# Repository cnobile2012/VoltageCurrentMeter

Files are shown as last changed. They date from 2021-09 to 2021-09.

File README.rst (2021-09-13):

*********************
Voltage Current Meter
*********************
The MIT License (MIT)

A circuit to show voltage and current on a TFT display. Parts can be added
using a small array of mounting holes on the board, plus two daughter boards
can be plugged into female connectors. There is an on board 5V to 3.3V
regulator which powers all components.

=====
KiCAD
=====

KiCAD files of the schematic and PCB.

==================
Setup Instructions
==================

  1. J1 - J8 are JST 1.5mm 3-pin connectors and are for the analog inputs or
     outputs of the 74HC4051 (8-Channel Analog Multiplexer/Demultiplexer).
  2. J9 is a screw terminal block for the circuits supply voltage.
  3. J10 is the Power Jumper. It allows the use of 5V on J9 or routes the
     V-IN on J9 to  a daughter board which can convert the voltage on J9 to 5V.
  4. J11 is a 4 pin standard female socket for the optional Daughter Board 1.
     This board can be used for external circuitry to convert any voltage to
     the 5 volts needed by the 3.3V regulator.
  5. J12 is a 12 pin standard female socket that provides the 2nd daughter
     board with all the control pins from the 74HC4051. It also provides the
     two pins not used on the Seeeduino XIAO plus ground and 3.3V power.

==============
PCBs Version 1
==============

=========
Schematic
=========

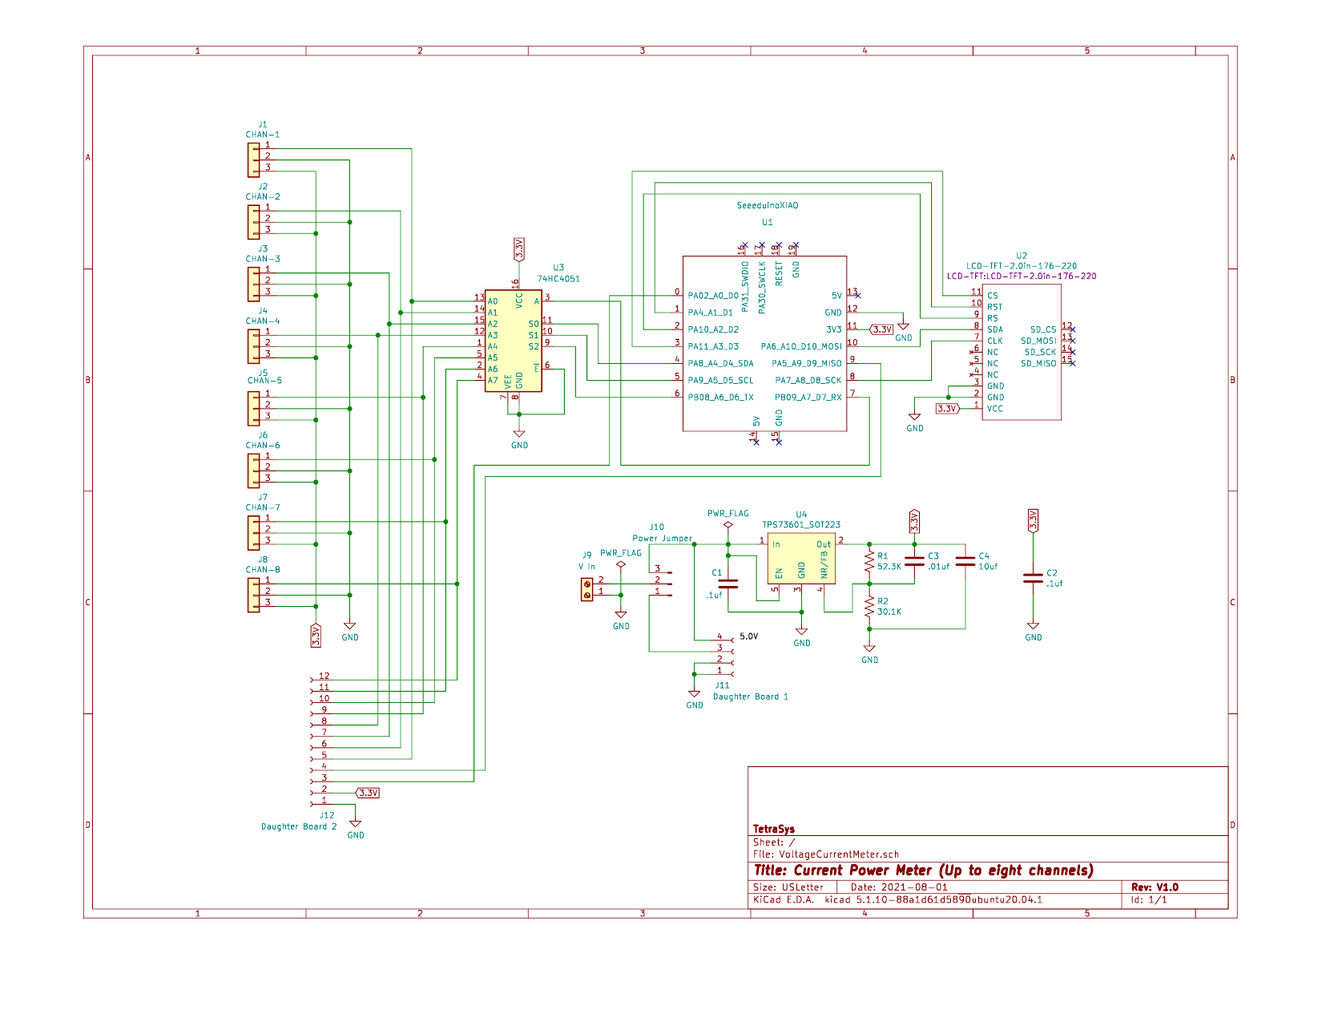
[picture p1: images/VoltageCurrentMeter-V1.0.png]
Schematic


================
Arduino Sketches
================

Below are the sketches that use this board.

--------------
BatteryCharger
--------------

This sketch displays the set voltage and current limited values and the actual
values while charging Li-Ion batteries. The charging voltage is adjustable to
12.6V (3 cells), 16.8V (4 cells), or 21.0V (5 cells) depending on the number of
cells. The default current is limited to 1250mA or can be set to adjustable
using a potentiometer.

Feel free to contact me at: carl dot nobile at gmail.com

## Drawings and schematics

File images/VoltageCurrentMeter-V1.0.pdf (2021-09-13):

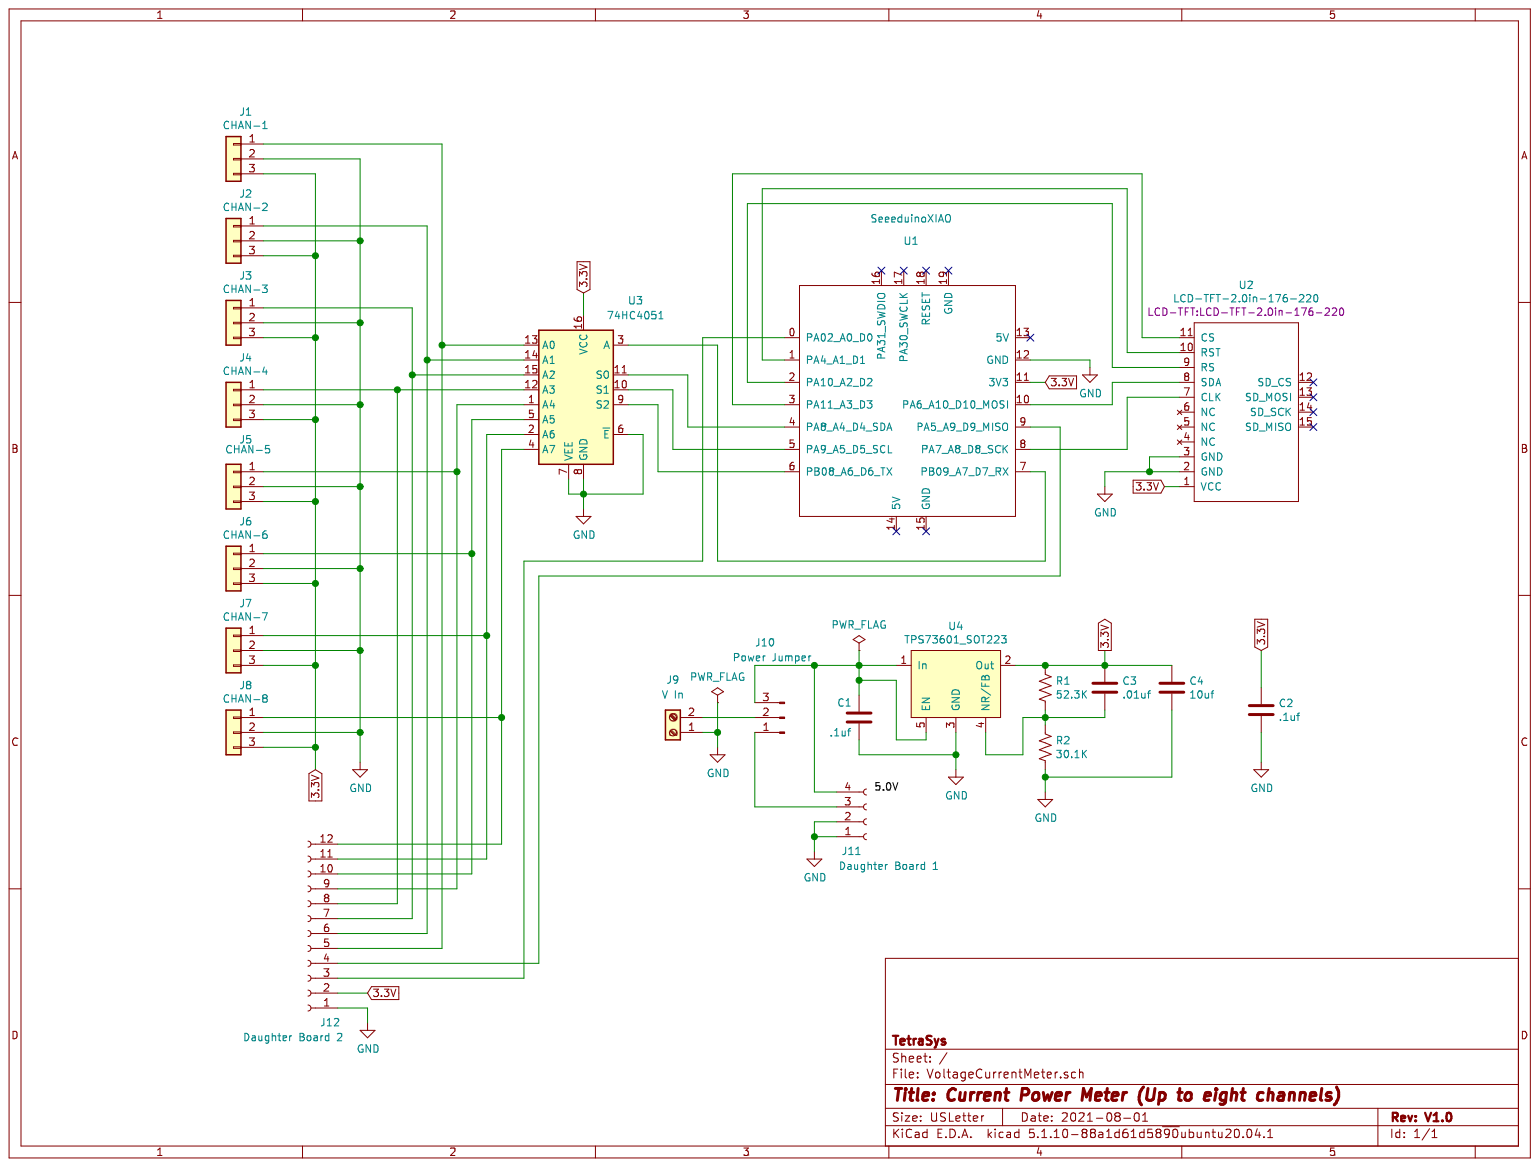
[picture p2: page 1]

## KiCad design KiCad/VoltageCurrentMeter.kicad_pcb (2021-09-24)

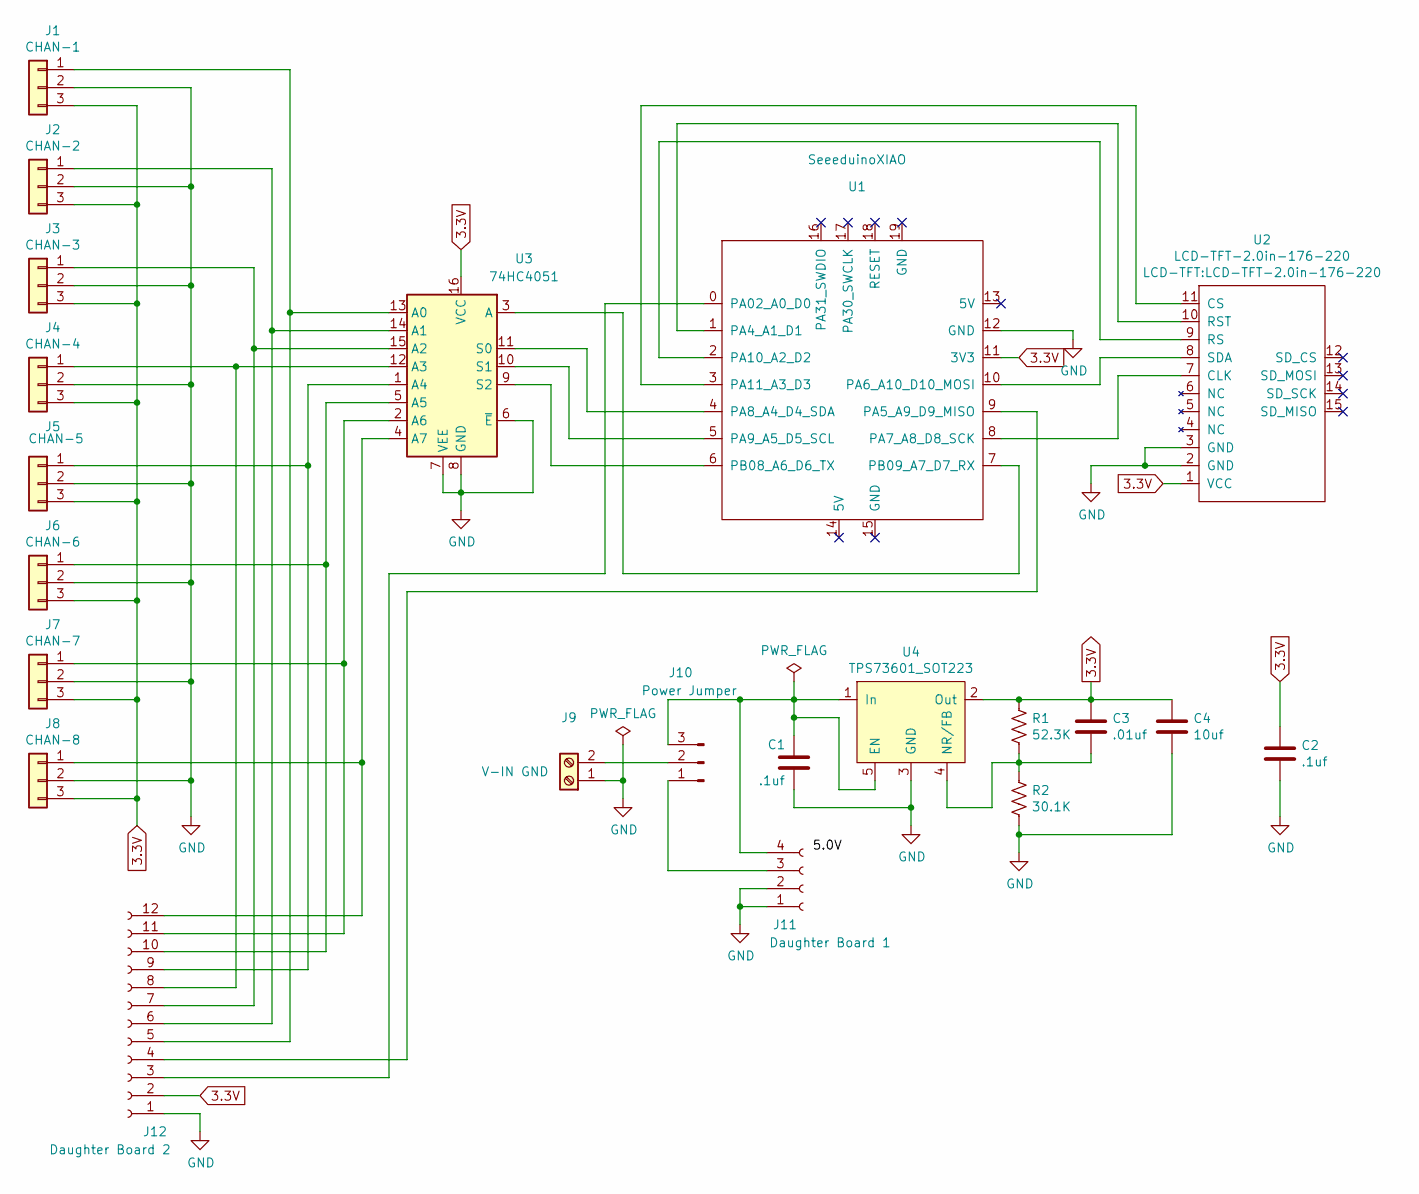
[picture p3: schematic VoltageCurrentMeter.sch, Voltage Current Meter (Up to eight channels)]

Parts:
C1, C2: .1uf; C_Disc_D4.7mm_W2.5mm_P5.00mm
C3: .01uf; C_Disc_D4.7mm_W2.5mm_P5.00mm
C4: 10uf; CP_Radial_D6.3mm_P2.50mm
J1: CHAN-1; JST_CJN_1x03_P1.50mm_Vertical
J2: CHAN-2; JST_CJN_1x03_P1.50mm_Vertical
J3: CHAN-3; JST_CJN_1x03_P1.50mm_Vertical
J4: CHAN-4; JST_CJN_1x03_P1.50mm_Vertical
J5: CHAN-5; JST_CJN_1x03_P1.50mm_Vertical
J6: CHAN-6; JST_CJN_1x03_P1.50mm_Vertical
J7: CHAN-7; JST_CJN_1x03_P1.50mm_Vertical
J8: CHAN-8; JST_CJN_1x03_P1.50mm_Vertical
J9: V-IN GND; TerminalBlock_Phoenix_MKDS-1,5-2-5.08_1x02_P5.08mm_Horizont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
J10: Power Jumper; PinHeader_1x03_P2.54mm_Vertical
J11: Daughter Board 1; PinSocket_1x04_P2.54mm_Vertical
J12: Daughter Board 2; PinSocket_1x12_P2.54mm_Vertical
R1: 52.3K; R_Axial_DIN0207_L6.3mm_D2.5mm_P10.16mm_Horizontal
R2: 30.1K; R_Axial_DIN0207_L6.3mm_D2.5mm_P10.16mm_Horizontal
U1: SeeeduinoXIAO; SeeeduinoXIAO-MOUDLE14P-2.54-21X17.8MM
U2: LCD-TFT-2.0in-176-220
U3: 74HC4051; SO-16_3.9x9.9mm_P1.27mm
U4: TPS73601_SOT223; SOT-223-6_TabPin3

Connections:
3.3V: C2.1, C3.1, C4.1, J1.3, J2.3, J3.3, J4.3, J5.3, J6.3, J7.3, J8.3, J12.2, R1.1, U1.11 (3V3), U2.1 (VCC), U3.16 (VCC), U4.2 (Out)
GND: C1.2, C2.2, C4.2, J1.2, J2.2, J3.2, J4.2, J5.2, J6.2, J7.2, J8.2, J9.1, J11.1, J11.2, J12.1, R2.2, U1.12 (GND), U2.2 (GND), U2.3 (GND), U3.6 (~E), U3.7 (VEE), U3.8 (GND), U4.3 (GND)
unnamed: C1.1, J10.3, J11.4, U4.1 (In), U4.5 (EN)
unnamed: C3.2, R1.2, R2.1, U4.4 (NR/FB)
unnamed: J1.1, J12.5, U3.13 (A0)
unnamed: J10.1, J11.3
unnamed: J9.2, J10.2
unnamed: J12.3, U1.0 (PA02_A0_D0)
unnamed: J12.4, U1.9 (PA5_A9_D9_MISO)
unnamed: J2.1, J12.6, U3.14 (A1)
unnamed: J3.1, J12.7, U3.15 (A2)
unnamed: J4.1, J12.8, U3.12 (A3)
unnamed: J5.1, J12.9, U3.1 (A4)
unnamed: J6.1, J12.10, U3.5 (A5)
unnamed: J7.1, J12.11, U3.2 (A6)
unnamed: J8.1, J12.12, U3.4 (A7)
unnamed: U1.1 (PA4_A1_D1), U2.10 (RST)
unnamed: U1.2 (PA10_A2_D2), U2.9 (RS)
unnamed: U1.3 (PA11_A3_D3), U2.11 (CS)
unnamed: U1.4 (PA8_A4_D4_SDA), U3.11 (S0)
unnamed: U1.5 (PA9_A5_D5_SCL), U3.10 (S1)
unnamed: U1.6 (PB08_A6_D6_TX), U3.9 (S2)
unnamed: U1.7 (PB09_A7_D7_RX), U3.3 (A)
unnamed: U1.8 (PA7_A8_D8_SCK), U2.7 (CLK)
unnamed: U1.10 (PA6_A10_D10_MOSI), U2.8 (SDA)

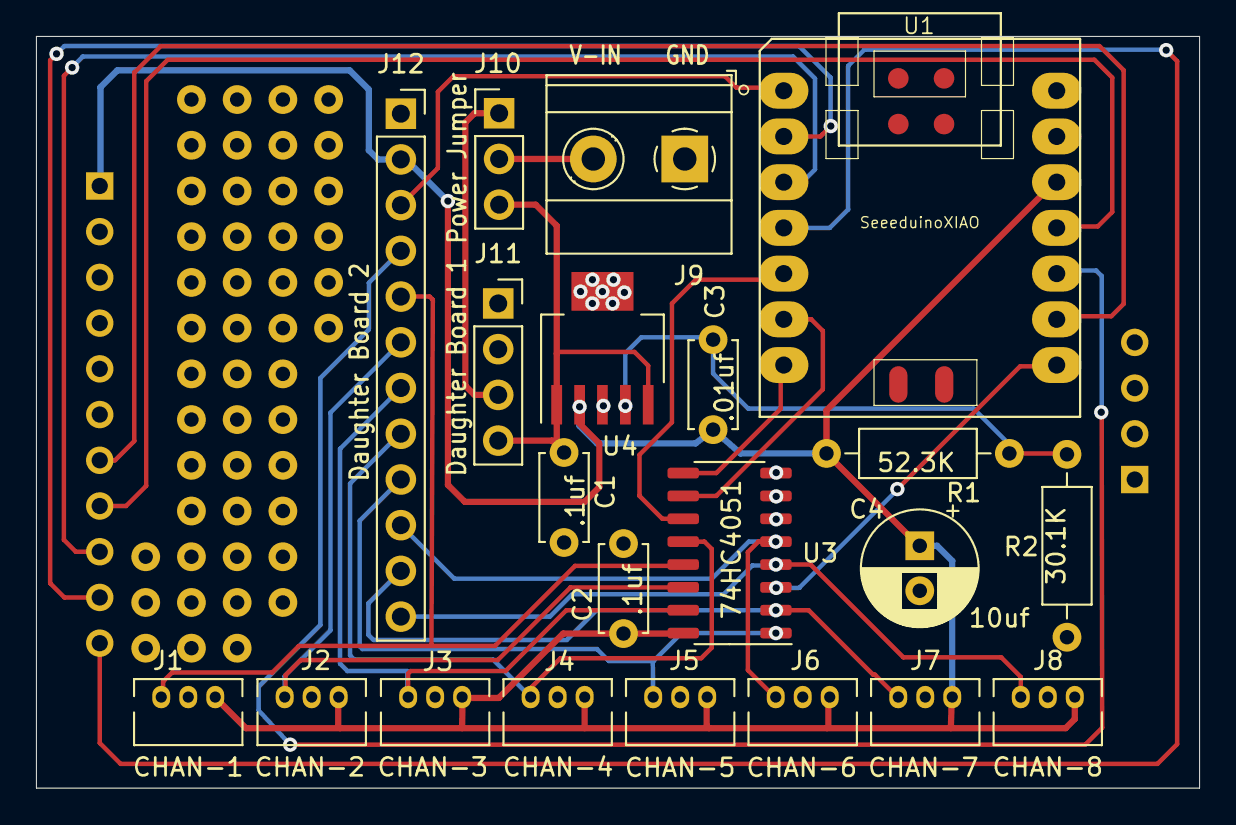
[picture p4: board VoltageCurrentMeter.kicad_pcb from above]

Board: 2 copper layers, 64.6 x 41.8 mm, 22 parts (1 on the bottom side), 25 nets.

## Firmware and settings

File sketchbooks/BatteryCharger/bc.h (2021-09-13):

/*
 * Battery Charger Header
 */

#ifndef  _BC_H
#define  _BC_H

#ifndef TFT_22_ILI9225_h
  #include <TFT_22_ILI9225.h>
#endif

typedef struct
  {
  String text;
  const GFXfont *f;
  uint16_t color;
  int16_t x1;
  int16_t y1;
  int16_t x2;
  int16_t y2;
  } MeterHeaderType;

typedef struct
  {
  String text;
  String old_text;
  bool changed;
  const GFXfont *f;
  uint16_t color;
  int16_t x;
  int16_t y;
  } MeterDataType;

/*
 * Configured for the Seeeduino XIAO
 */
#define TFT_RST 1  // D1
#define TFT_RS  2  // D3
#define TFT_CS  3  // D2
#define TFT_SDI 10 // MOSI
#define TFT_CLK 8  // SCK
#define TFT_LED 0  // D0 -- NC if wired to +3.3V internally.

#define PIN_S0  4  // D4
#define PIN_S1  5  // D5
#define PIN_S2  6  // D6
#define ADC_PIN 7  // A7 (ADC pin)

#define TFT_BRIGHTNESS 200 // Initial brightness of TFT backlight (optional)
#define DEFAULT_METER_COLOR COLOR_GOLD
#define DEFAULT_BACKGROUND_COLOR COLOR_BLACK
#define ERROR_COLOR COLOR_RED

#define NUM_ITEMS(a) (sizeof(a) / sizeof(*a))

#define HEADER_STRUCT_SIZE 4
#define METER_DATA_ARRAY_SIZE 4
// MUX_74HC4051_SIZE -- Voltage, Current, and a switch to
// set voltage and current values.
#define MUX_74HC4051_SIZE 4
#define NUM_READS 200

/*
 * Prototypes
 */
void populateDisplays(void);
void drawHeaders(void);
void initialPopulateData(void);
void drawData(uint16_t color);
void selectChannel(byte counter);
void setChanged(MeterDataType *data, String sensor, uint16_t cn);
uint16_t incSelectCount(uint16_t average, uint16_t select, uint16_t max);
void setVoltage(uint16_t vSelect);
void setCurrent(uint16_t cSelect);

#endif /* _BC_H */

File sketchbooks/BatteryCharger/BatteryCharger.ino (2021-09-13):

// Include application, user and local libraries
//#include <SPI.h>
#include <TFT_22_ILI9225.h>

// This code works with the 2.0in Arduino Color LCD Modual from 
// Include font definition files
// NOTE: These files may not have all characters defined! Check the GFXfont def
// params 3 + 4, e.g. 0x20 = 32 = space to 0x7E = 126 = ~

/*
 * To create these fonts go to http://oleddisplay.squix.ch/#/home
 * Choose the TFT display under Preview Display.
 * Choose "Adafruit GTX Font" under the "Library Version".
 * The rest should be obvious.
 * Copy-n-past to a file as named in the #include below.
 */
#include "Roboto_Mono_Bold_16.h"
#include "Roboto_Mono_Bold_15.h"
#include "bc.h"

#define DEBUG true

// Use hardware SPI (faster - on Uno: 13-SCK, 12-MISO, 11-MOSI)
TFT_22_ILI9225 tft = TFT_22_ILI9225(TFT_RST, TFT_RS, TFT_CS,
                                    TFT_LED, TFT_BRIGHTNESS);
// Use software SPI (slower)
//TFT_22_ILI9225 tft = TFT_22_ILI9225(
//  TFT_RST, TFT_RS, TFT_CS, TFT_SDI, TFT_CLK, TFT_LED,
//  TFT_BRIGHTNESS);

// Variables and constants
MeterHeaderType headers[HEADER_STRUCT_SIZE];
MeterDataType meter_data[METER_DATA_ARRAY_SIZE];
const double resConvert = 4095.0; // 12 bit ADC counts

void setup()
  {
#if DEBUG == true
  SerialUSB.begin(115200);
  //while(!SerialUSB);
#endif
  // Set analog input resolution to max, 12-bits
  analogReadResolution(12);
  // Config 74HC4051 address select pins.
  pinMode(PIN_S0, OUTPUT);
  pinMode(PIN_S1, OUTPUT);
  pinMode(PIN_S2, OUTPUT);
  // Start the TFT LCD display
  tft.begin();
  tft.clear();
  //tft.setBackgroundColor(DEFAULT_BACKGROUND_COLOR);
  // 0=portrait, 1=right rotated landscape, 2=reverse portrait,
  // 3=left rotated landscape
  tft.setOrientation(1);
  populateHeaders();
  initialPopulateData();
  // Draw the header voltage, current, and power strings.
  drawHeaders();
  }

void populateHeaders()
  {
  headers[0].text = "Constant";
  headers[0].f = &Roboto_Mono_Bold_16;
  headers[0].color = COLOR_CYAN;
  headers[0].x1 = 65;
  headers[0].y1 = 0;
  headers[0].x2 = 0;
  headers[0].y2 = 0;
  headers[1].text = "Current & Voltage";
  headers[1].f = &Roboto_Mono_Bold_16;
  headers[1].color = COLOR_CYAN;
  headers[1].x1 = 10;
  headers[1].y1 = 15;
  headers[1].x2 = 0;
  headers[1].y2 = 0;
  headers[2].text = ""; // Horizontal Title Line
  headers[2].f = NULL;
  headers[2].color = COLOR_CYAN;
  headers[2].x1 = 0;
  headers[2].y1 = 33;
  headers[2].x2 = 220;
  headers[2].y2 = 33;
  headers[3].text = "Set Values  Actual";
  headers[3].f = &Roboto_Mono_Bold_15;
  headers[3].color = COLOR_YELLOW;
  headers[3].x1 = 5;
  headers[3].y1 = 38;
  headers[3].x2 = 0;
  headers[3].y2 = 0;
  }

void drawHeaders()
  {
  int16_t y, w, h;

  for (uint16_t i = 0; i < NUM_ITEMS(headers); i++)
    {
    if (headers[i].text == "")
      {
      tft.drawLine(headers[i].x1, headers[i].y1, headers[i].x2,
                   headers[i].y2, headers[i].color);
      }
    else
      {
      // Draw the header text.
      tft.setGFXFont(headers[i].f); // Set current font
      // Get string extents
      tft.getGFXTextExtent(headers[i].text, headers[i].x1,
                           headers[i].y1, &w, &h);
      y = headers[i].y1 + h;
      // Print the string to the LCD TFT.
      tft.drawGFXText(headers[i].x1, y, headers[i].text,
                      headers[i].color);
      }
    }
  }

void initialPopulateData(void)
  {
  meter_data[0].text = ""; // Set Voltage
  meter_data[0].changed = true;
  meter_data[0].f = &Roboto_Mono_Bold_16;
  meter_data[0].color = COLOR_YELLOW;
  meter_data[0].x = 10;
  meter_data[0].y = 80;
  meter_data[1].text = ""; // Set Current
  meter_data[1].changed = true;
  meter_data[1].f = &Roboto_Mono_Bold_16;
  meter_data[1].color = COLOR_YELLOW;
  meter_data[1].x = 10;
  meter_data[1].y = 120;
  meter_data[2].text = ""; // Actual Voltage
  meter_data[2].changed = true;
  meter_data[2].f = &Roboto_Mono_Bold_16;
  meter_data[2].color = COLOR_YELLOW;
  meter_data[2].x = 139;
  meter_data[2].y = 80;
  meter_data[3].text = ""; // Actual Current
  meter_data[3].changed = true;
  meter_data[3].f = &Roboto_Mono_Bold_16;
  meter_data[3].color = COLOR_YELLOW;
  meter_data[3].x = 139;
  meter_data[3].y = 120;
  }

void loop()
  {
  double sensorData[MUX_74HC4051_SIZE] = {0.0, 0.0, 0,  0};
  //                                       V    C  vSW cSW
  int average;
  double total;
  static uint16_t cSelect = 0, vSelect = 0;

  for (byte sensorCount = 0; sensorCount < MUX_74HC4051_SIZE; sensorCount++)
    {
    selectChannel(sensorCount);
    total = 0.0;

    for (int i = 0; i < NUM_READS; i++)
      {
      average = analogRead(ADC_PIN);
      total += average;
      delay(2);
      }

    average = total / NUM_READS;
#if DEBUG == true
      SerialUSB.print("ADC Average (");
      SerialUSB.print(sensorCount);
      SerialUSB.print("): ");
      SerialUSB.println(average);
#endif

    if (sensorCount == 0) // Actual Voltage
      {
      // For zero reference use 125 and (resConvert / 26 [max voltage swing -1 to 25])
      sensorData[sensorCount] = ((average - 125) / (resConvert / 26));
      setChanged(meter_data, String("") + sensorData[sensorCount] + 'V', 2);
      }
    else if (sensorCount == 1) // Actual Current
      {
      // For zero reference use 1933 and (35.67567 = 3.3V/0.185A*2).
      sensorData[sensorCount] = ((average - 1933) * (35.67567 / resConvert));
      setChanged(meter_data, String("") + sensorData[sensorCount] + 'A', 3);
#if DEBUG == true
      //SerialUSB.print("  Current: ");
      //SerialUSB.println(sensorData[sensorCount]);
#endif
      }
    else if (sensorCount == 2) // Voltage Switch
      {
      // Read three states then loop.
      vSelect = incSelectCount(average, vSelect, 3);
      setVoltage(vSelect);
      }
    else if (sensorCount == 3) // Current Switch
      {
      // Read two states then loop.
      cSelect = incSelectCount(average, cSelect, 2);
      setCurrent(cSelect);
      }
#if DEBUG == true
    else
      {
      SerialUSB.print("Invalid sensorCount: ");
      SerialUSB.println(sensorCount);
      }
#endif
    }

  drawData(DEFAULT_METER_COLOR);
  delay(400);
  }

void selectChannel(byte counter)
  {
  bool S0 = bool(counter >> 0 & 0x01);
  bool S1 = bool(counter >> 1 & 0x01);
  bool S2 = bool(counter >> 2 & 0x01);

  digitalWrite(PIN_S0, S0);
  digitalWrite(PIN_S1, S1);
  digitalWrite(PIN_S2, S2);
  }

void setChanged(MeterDataType *data, String sensor, uint16_t cnt)
  {
  if (data[cnt].text == sensor)
    {
    data[cnt].changed = false;
    }
  else
    {
    meter_data[cnt].changed = true;
    meter_data[cnt].old_text = data[cnt].text;
    }

   meter_data[cnt].text = sensor;
  }

void drawData(uint16_t color)
  {
  int16_t y, w, h;

  for (uint16_t i = 0; i < NUM_ITEMS(meter_data); i++)
    {
    if (meter_data[i].changed)
      {
      // Set current font
      tft.setGFXFont(meter_data[i].f);
      // Get string extents
      tft.getGFXTextExtent(meter_data[i].old_text, meter_data[i].x,
                           meter_data[i].y, &w, &h);
      y = meter_data[i].y + h;
      tft.drawGFXText(meter_data[i].x, y, meter_data[i].old_text,
                      DEFAULT_BACKGROUND_COLOR);
      // Print string
      tft.getGFXTextExtent(meter_data[i].text, meter_data[i].x,
                           meter_data[i].y, &w, &h);
      y = meter_data[i].y + h;
      tft.drawGFXText(meter_data[i].x, y, meter_data[i].text, color);
      }
    //else
    //  {
    //  SerialUSB.println(meter_data[i].text);
    //  }
    }
  }

uint16_t incSelectCount(int average, uint16_t select, uint16_t max)
  {
  if (average >= 3000)
    {
    uint16_t count = select + 1;
    select = (count < max) ? count : 0;
#if DEBUG == true
    SerialUSB.print("Average: (");
    SerialUSB.print(max == 2 ? "I): " : "V): ");
    SerialUSB.print(average);
    SerialUSB.print(", Select: ");
    SerialUSB.println(select);
#endif
    }

  return select;
  }

void setVoltage(uint16_t vSelect)
  {
  static String voltages[] = {"12.6V", "16.8V", "21.0V"};
  setChanged(meter_data, voltages[vSelect], 0);

  }

void setCurrent(uint16_t cSelect)
  {
  static String status[] = {"1250mA", "ADJUSTABLE"};
  setChanged(meter_data, status[cSelect], 1);
  //SerialUSB.print("Old test: ");
  //SerialUSB.print(meter_data[1].old_text);
  //SerialUSB.print(", Current text: ");
  //SerialUSB.print(meter_data[1].text);
  //SerialUSB.print(", changed: ");
  //SerialUSB.println(meter_data[1].changed);

  }

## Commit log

2021-09-13 Updates to schematic and added images and a README.
    [VoltageCurrentMeter.kicad_pcb, VoltageCurrentMeter.sch]
2021-09-13 Bumped up the schematic width.
2021-09-13 Renamed the gerber files and updated the README.
    [VoltageCurrentMeter-B_Cu.gbr, VoltageCurrentMeter-B_Mask.gbr, VoltageCurrentMeter-B_Paste.gbr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]
2021-09-13 Added an Arduino sketch and updated the README.
2021-09-13 Updated the gerber files.
    [VoltageCurrentMeter-B_Cu.gbr, VoltageCurrentMeter-B_Mask.gbr, VoltageCurrentMeter-B_Paste.gbr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]
2021-09-24 Fixed an issue where the pins on the Seeeduino XIAO were a little too far apart.
    [VoltageCurrentMeter-B_Cu.gbr, VoltageCurrentMeter-B_Mask.gbr, VoltageCurrentMeter-B_Paste.gbr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]
